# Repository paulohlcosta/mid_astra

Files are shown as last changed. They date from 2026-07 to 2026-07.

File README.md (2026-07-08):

Fazer a leitura dos sinais do computador de bordo MID do Astra - 1999 a 2011.

Provavelmente você sabe de algum astra que tem o computador de bordo defeituoso. O equipamento original usa lâmpadas halógenas que geram muito calor e uma tela LCD super delicada.
Com um Arduino e algum circuito eletrônico, estou trabalhando numa alternativa para esse equipamento.

[NotebookLM do estudo:](https://notebooklm.google.com/notebook/e0c29d24-7539-4ca7-bbeb-1d556da1ff12)

Melhor referência que encontrei até o momento: <https://github.com/fire1/ArduinoMid>

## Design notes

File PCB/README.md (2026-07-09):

Esquemáticos para impressão da PCB e seus componentes.

Diagrama eletrônico do circuito.

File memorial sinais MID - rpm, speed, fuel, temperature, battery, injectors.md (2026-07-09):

# Technical Memorial: Signal Characterization — Astra MID Reader (Phase 1)

**Device:** Arduino Nano (ATmega328P, 16MHz) / **Vehicle:** Brazilian 1999 Chevrolet Astra (ECM Bosch Motronic 1.5.5) with MID.

---

### PIN 2 — PIN_TACHO

* **Signal description:** Engine crankshaft rotation frequency (tachometer).
* **Signal origin:** Negative square wave emitted by the ECU, conditioned and inverted by an optocoupler PC817 before reaching the Arduino. The resulting signal at the Arduino pin is a positive square wave, active HIGH at rest (`INPUT_PULLUP`), pulsing LOW on each engine event.
* **Electrical characteristics:** Signal shared with the OEM instrument cluster stepper motor driver. Series resistor 10kΩ on optocoupler LED input. Optocoupler collector pulled up internally by Arduino `INPUT_PULLUP` (~50kΩ to 5V). Pull-up resistor on optocoupler LED side measured at ~2.2kΩ recommended for reliable LED saturation at 5mA.
* **Observed behavior:** At idle (~950–1000 RPM), period measured at ~31.500µs (~31.7Hz). At 2600 RPM, period drops to ~11.500µs (~86Hz). Signal is stable and consistent across sessions. Pulse count per window of 500ms at idle: 16–19 pulses, consistent with ~32Hz and two pulses per crankshaft revolution (motor 4-cylinder, 2 events per cycle). Between 15 and 150 pulses can occur within each 500ms interval depending on engine speed.
* **Interrupt:** External interrupt INT0, FALLING edge, `attachInterrupt()`.
* **RPM calculation:** $$\text{RPM} = \frac{60 \times 10^6}{\text{period}(\mu\text{s}) \times N_{\text{teeth}}}$$
  where $N_{\text{teeth}}$ is the number of reluctor teeth per revolution — confirmed empirically at 2 events/rev for this engine.
* **Notes for future development:** This signal is reliable and fully characterized. For a future OBD computer, this pin can directly drive RPM display, shift-light logic, and engine load calculations. Timer Input Capture (ICP1, pin 8) should be preferred over external interrupt in a redesign, as it timestamps edges in hardware with zero jitter, freeing CPU cycles and improving accuracy at high RPM.

---

### PIN 3 — PIN_SPEED

* **Signal description:** Vehicle road speed (speedometer).
* **Signal origin:** Presumably identical architecture to PIN_TACHO — negative square wave from ECU, conditioned via optocoupler, shared with OEM instrument cluster.
* **Electrical characteristics:** Same isolation and protection scheme as PIN_TACHO. `INPUT_PULLUP` active.
* **Observed behavior:** Signal confirmed functional during vehicle movement. The frequency of pulses can be user to determine vehycle speed.
* **Interrupt:** External interrupt INT1, FALLING edge, `attachInterrupt()`.
* **Speed calculation:** $$V_{\text{km/h}} = \frac{3600 \times 10^6}{\text{period}(\mu\text{s}) \times K}$$
  where $K$ is the pulses-per-kilometer constant. For this project $K$ = 15600.

---

### PIN 5 — PIN_TEMP_PWM

* **Signal description:** Engine coolant temperature indicator, as seen by the OEM instrument cluster stepper motor driver.
* **Signal origin:** PWM signal generated internally by the OEM instrument cluster to drive the stepper motor of the temperature gauge. The ECU sends temperature data to the cluster via a separate bus (likely serial or analog); the cluster translates this into a PWM duty cycle to position the stepper motor pointer. The Arduino taps this PWM line directly at the cluster connector.
* **Electrical characteristics:** No optocoupler isolation. Signal voltage is 5V-compatible (cluster logic level). `INPUT_PULLUP` active. Signal absent (pin stays HIGH via pull-up) when cluster is unpowered or when coolant temperature is below the gauge's lower threshold (~70°C), because the stepper motor driver receives no movement command in that range.
* **Observed behavior:**

| Temperature (°C) | TEMP_PWM Duty (%) | Observation |
| :--- | :--- | :--- |
| <70 (cold engine) | 90.2% (fixed) | Pointer at rest, no stepper command |
| 70 | 89.5% | Pointer begins to move |
| 80 | 72.0% | Normal operating range |
| 85 | 64.0% | Radiator fan #1 activated by ECU |
| ~90 (extrapolated) | ~55% | Estimated, not yet logged |

* **Signal period:** stable at ~9.920–9.940µs (~100Hz) across all conditions. This frequency is the fixed oscillator clock of the stepper motor driver IC inside the cluster. The duty cycle encodes the pointer position command.
* **Logic polarity:** Signal is logically inverted relative to temperature. Higher temperature → lower duty cycle. With `INPUT_PULLUP`, the duty measured is the HIGH time; the ECU-commanded LOW time increases with temperature. Effective temperature-encoding duty: $\text{duty\_real} = 100\% - \text{duty\_measured}$.
* **Read method:** `pulseIn()` executed once every 10 seconds (`TEMP_INTERVAL`), to avoid blocking the main loop and corrupting `INJ_PULSE` capture. This cadence is more than sufficient given the thermal time constant of the cooling system (observed ~4 minutes from 70°C to 85°C).
* **Notes for future development:** A multi-point calibration table mapping $\text{duty\_real} to °C should be built from controlled logged sessions with a reference thermometer. Preliminary curve suggests linear or mildly nonlinear behavior between 70°C and ~110°C. The 100Hz fixed period is a reliable sanity-check signal — if period deviates significantly from ~10ms, it indicates cluster power loss or hardware fault. In a redesign, this pin should be read via PCINT2 with asynchronous edge capture to completely eliminate `pulseIn()` blocking.

---

### PIN 8 — PIN_INJECTOR

* **Signal description:** Fuel injector signal analysis.
* **Signal origin:** Negative pulse signal from ECU driving the fuel injectors. Signal is non-periodic — each pulse is an independent event corresponding to one injection event. The injector pulse duration is fixed, meaning that only the pulse frequency varies to control fuel delivery; higher frequency indicates higher fuel consumption. Signal conditioned via optocoupler PC817.
* **Electrical characteristics:** Same optocoupler isolation as TACHO. `INPUT_PULLUP` active. With `INPUT_PULLUP`, pin rests HIGH; injector opening event pulls pin LOW.
* **Observed behavior:** Between 15 and 150 injector pulses can occur within each 500ms measurement window. Current baseline calculation assumes a consumption rate of 22,700 pulses per liter of fuel injected, although this scaling factor can be modified or calibrated later.
* **Notes for future development:** This hardware channel requires the use of **Timer1 Input Capture (ICP1)** to properly monitor the incoming pulse events without missing rapid triggers.

---

### PIN A2 — PIN_BATT

* **Signal description:** Vehicle electrical system voltage (battery / alternator).
* **Signal origin:** Direct resistive voltage divider tap from the vehicle 12V bus. No isolation.
* **Electrical characteristics:** Voltage divider ratio calibrated empirically. Observed range: 0.00V (ignition off, Arduino unpowered) to 14.09V (alternator charging at ~2600 RPM). Resting battery voltage: ~12.20–12.23V (engine off, ignition on). Charging voltage: 13.60–14.09V (engine running, consistent with a healthy alternator regulator setpoint of ~14.2V ±0.3V).
* **Observed behavior:** Voltage drop to ~10.14V observed at engine crank (starter motor inrush current). Instantaneous drop to ~13.60–13.68V correlated with radiator fan activation, consistent with ~15–20A fan motor load. Voltage collapse to ~1.09V immediately at ignition key-off, reaching 0.00V within ~1.5 seconds as filter capacitors discharge.
* **Notes for future development:** ADC reference on the Arduino Nano is tied to VCC (5V), which itself may fluctuate with USB/vehicle supply variations. For improved accuracy, use the internal 1.1V bandgap reference with a better-ratio divider, or use an external precision voltage reference (e.g., LM4040). A low-pass RC filter (e.g., 10kΩ + 100µF) on the divider output will suppress alternator ripple and starter transients before the ADC pin.

---

### PIN A0 — PIN_FUEL

* **Signal description:** Fuel tank level.
* **Signal origin:** Potentiometer-type resistive sensor inside the fuel tank. Voltage read via resistive divider at the instrument cluster signal line.
* **Electrical characteristics:** No isolation. Voltage range observed: 5.82V–6.88V across all sessions, with the vehicle presumably at a fixed fuel level (parked). Divider ratio not yet calibrated against a known fuel level.
* **Observed behavior:** Signal is stable with low noise at rest. Minor fluctuations of ±0.06V observed, likely due to ADC noise and small variations in the vehicle supply. No sloshing artifact observed (vehicle stationary throughout all logged sessions).
* **Notes for future development:** Fuel sender resistance curves are nonlinear and vehicle-specific. A minimum 5-point calibration table (empty, 1/4, 1/2, 3/4, full) is required, measured with a reference fuel gauge and known tank volumes. Implement a software moving-average filter (8–16 samples) to suppress sloshing noise during vehicle movement. The observed voltage range of ~5.82–6.88V suggests the divider ratio needs adjustment to use the full ADC range (0–5V), improving resolution from the current ~12-bit effective range to the full 10-bit ADC range.

---

### General Notes for Future On-Board Computer Development

The signal set captured is sufficient to compute in real time: engine RPM, vehicle speed, coolant temperature (after calibration), fuel level (after calibration), battery state, injector frequency, and estimated fuel consumption (based on the fixed pulse-per-liter calculation).

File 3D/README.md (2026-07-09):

Arquivos desenhados para impressão em 3D, prototipagem e afins.

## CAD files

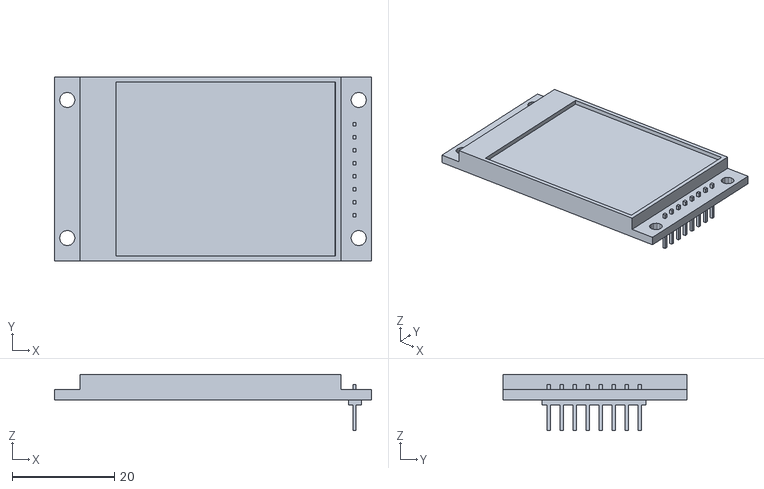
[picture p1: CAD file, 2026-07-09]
3D/display ST7789 2.0inch.stl
62.0 x 36.0 x 11.0

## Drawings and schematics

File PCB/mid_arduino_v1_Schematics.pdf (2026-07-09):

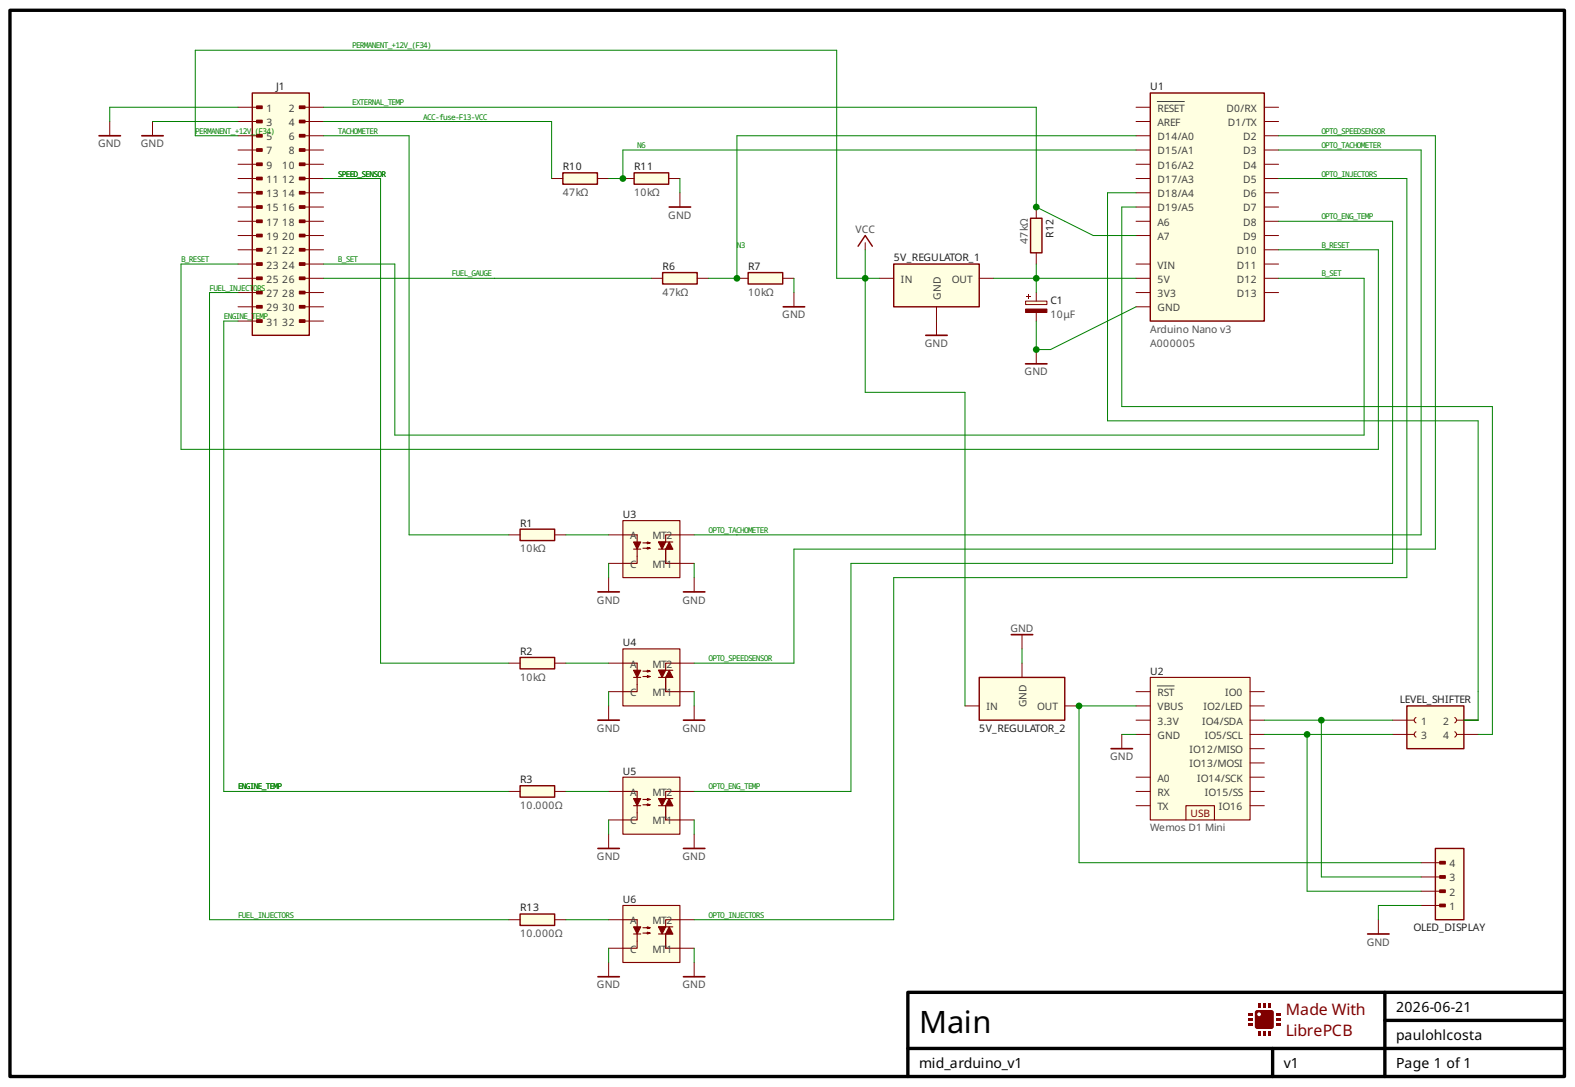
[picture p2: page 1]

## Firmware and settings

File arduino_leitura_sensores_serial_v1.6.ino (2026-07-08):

/*
 * Astra MID Reader - Fase 1 - Rev C
 * Monitora: tacômetro, velocidade, temperatura (PWM), injetor, bateria e combustível.
 * Pinos: TACHO=2 (INT0), SPEED=3 (INT1), TEMP_PWM=5, INJECTOR=8 (ICP1), BATT=A2, FUEL=A0.
 * Injetor usa Timer1 Input Capture (ICP1, pino 8) com alternância de borda por hardware.
 * Optoacoplador PC817 com pull-up: injetor ativo = pino LOW, repouso = HIGH.
 * Borda de DESCIDA = início do pulso, borda de SUBIDA = fim do pulso.
 * Período (descida a descida) e largura calculados inteiramente na ISR via Timer1.
 * Prescaler 8 → resolução 0,5µs por tick. Overflow (~32ms) tratado via contador de 32 bits.
 * TEMP_PWM lido com pulseIn a cada TEMP_INTERVAL ms para minimizar bloqueio no loop.
 * TACHO e SPEED com timeout de 2s para zerar leitura quando sem pulsos.
 * BUTTON_A=D10, BUTTON_B=D12: botões momentâneos que fecham com GND (INPUT_PULLUP).
 */

// -----------------------------------------------------------------------------
// Pinagem
// -----------------------------------------------------------------------------
#define PIN_TACHO       2
#define PIN_SPEED       3
#define PIN_TEMP_PWM    5
#define PIN_INJECTOR    8    // ICP1 — fixo no hardware do ATmega328P
#define PIN_BATT       A2
#define PIN_FUEL       A0
#define PIN_BUTTON_A   10   // Botão A — fecha com GND
#define PIN_BUTTON_B   12   // Botão B — fecha com GND

// -----------------------------------------------------------------------------
// Constantes
// -----------------------------------------------------------------------------
#define TIMEOUT_US          2000000UL
#define INJ_PULSE_MIN_US        200UL   // µs mínimo aceitável
#define INJ_PULSE_MAX_US     200000UL   // µs máximo — filtra injetor travado aberto
#define INJ_HIST                    8
#define LOOP_INTERVAL             200   // ms
#define TEMP_INTERVAL           10000UL
#define PULSEIN_TIMEOUT         30000UL
#define INJ_TIMEOUT_OVF          61UL   // ~2s em overflows do Timer1 (prescaler 8)

// -----------------------------------------------------------------------------
// Variáveis TACHO
// -----------------------------------------------------------------------------
volatile unsigned long tachoLastTime = 0;
volatile unsigned long tachoPeriod   = 0;
volatile unsigned int  tachoPulsos   = 0;

// -----------------------------------------------------------------------------
// Variáveis SPEED
// -----------------------------------------------------------------------------
volatile unsigned long speedLastTime = 0;
volatile unsigned long speedPeriod   = 0;
volatile unsigned int  speedPulsos   = 0;

// -----------------------------------------------------------------------------
// Variáveis INJECTOR (ICP1)
// -----------------------------------------------------------------------------
volatile uint32_t injOverflowCount  = 0;
volatile uint32_t injTicksFall      = 0;
volatile uint32_t injTicksPrevFall  = 0;
volatile unsigned long injPulseUs   = 0;
volatile unsigned long injPeriodUs  = 0;
volatile bool          injReady     = false;
volatile bool          injWaitingRise = false;
volatile unsigned long injHistory[INJ_HIST];
volatile uint8_t       injHistIdx   = 0;
volatile uint32_t      injLastValidOvf = 0;
float fator_consumo = 22700.0;

// -----------------------------------------------------------------------------
// Variáveis TEMP_PWM
// -----------------------------------------------------------------------------
float tempDutyCache    = -1.0;
float tempPeriodoCache =  0.0;
bool  tempValido       = false;

// -----------------------------------------------------------------------------
// ISR — TACHO (INT0, pino 2, FALLING)
// -----------------------------------------------------------------------------
void isrTacho() {
  unsigned long agora = micros();
  tachoPeriod   = agora - tachoLastTime;
  tachoLastTime = agora;
  tachoPulsos++;
}

// -----------------------------------------------------------------------------
// ISR — SPEED (INT1, pino 3, FALLING)
// -----------------------------------------------------------------------------
void isrSpeed() {
  unsigned long agora = micros();
  speedPeriod   = agora - speedLastTime;
  speedLastTime = agora;
  speedPulsos++;
}

// -----------------------------------------------------------------------------
// ISR — Timer1 Overflow
// -----------------------------------------------------------------------------
ISR(TIMER1_OVF_vect) {
  injOverflowCount++;
}

// -----------------------------------------------------------------------------
// ISR — Timer1 Input Capture
// PC817 com pull-up: repouso=HIGH, injetor ativo=LOW
//   borda de DESCIDA (ICES1=0) → início do pulso → salva ticks, alterna para subida
//   borda de SUBIDA  (ICES1=1) → fim do pulso    → calcula largura e período
// -----------------------------------------------------------------------------
ISR(TIMER1_CAPT_vect) {
  uint16_t captura  = ICR1;
  uint32_t ovfLocal = injOverflowCount;

  if ((TIFR1 & (1 << TOV1)) && captura < 0x8000) {
    ovfLocal++;
  }

  uint32_t ticksAgora = (ovfLocal << 16) | captura;

  if (!injWaitingRise) {
    injTicksPrevFall = injTicksFall;
    injTicksFall     = ticksAgora;
    injWaitingRise   = true;
    TCCR1B |= (1 << ICES1);
  } else {
    injWaitingRise = false;
    TCCR1B &= ~(1 << ICES1);

    uint32_t ticksPulso = ticksAgora - injTicksFall;
    unsigned long larguraUs = ticksPulso >> 1;

    if (larguraUs >= INJ_PULSE_MIN_US && larguraUs <= INJ_PULSE_MAX_US) {
      injPulseUs = larguraUs;

      if (injTicksPrevFall > 0) {
        uint32_t ticksPeriodo = injTicksFall - injTicksPrevFall;
        injPeriodUs = ticksPeriodo >> 1;
      }

      injHistory[injHistIdx % INJ_HIST] = larguraUs;
      injHistIdx++;
      injReady = true;
      injLastValidOvf = ovfLocal;
    }
  }
}

// -----------------------------------------------------------------------------
// Leitura TEMP_PWM
// -----------------------------------------------------------------------------
void atualizarTempPWM() {
  unsigned long high = pulseIn(PIN_TEMP_PWM, HIGH, PULSEIN_TIMEOUT);
  unsigned long low  = pulseIn(PIN_TEMP_PWM, LOW,  PULSEIN_TIMEOUT);

  if (high == 0 && low == 0) {
    tempDutyCache    = -1.0;
    tempPeriodoCache =  0.0;
    tempValido       = false;
    return;
  }

  unsigned long periodo = high + low;
  tempDutyCache    = (periodo > 0) ? (float)high / periodo * 100.0 : -1.0;
  tempPeriodoCache = (float)periodo;
  tempValido       = true;
}

// -----------------------------------------------------------------------------
// Setup
// -----------------------------------------------------------------------------
void setup() {
  Serial.begin(115200);

  pinMode(PIN_TACHO,    INPUT_PULLUP);
  pinMode(PIN_SPEED,    INPUT_PULLUP);
  pinMode(PIN_TEMP_PWM, INPUT_PULLUP);
  pinMode(PIN_INJECTOR, INPUT_PULLUP);
  pinMode(PIN_BUTTON_A, INPUT_PULLUP);
  pinMode(PIN_BUTTON_B, INPUT_PULLUP);

  attachInterrupt(digitalPinToInterrupt(PIN_TACHO), isrTacho, FALLING);
  attachInterrupt(digitalPinToInterrupt(PIN_SPEED), isrSpeed, FALLING);

  TCCR1A = 0;
  TCCR1B = 0;
  TCCR1B |= (1 << CS11);
  TIMSK1 |= (1 << ICIE1);
  TIMSK1 |= (1 << TOIE1);

  atualizarTempPWM();

  Serial.println("@");
  Serial.print(F("=== ASTRA MID READER - FASE 1 Rev C ==="));
  Serial.println(__FILE__);
  Serial.println(F("Aguardando sinais..."));
  Serial.println(F("--------------------------------------------------"));
  Serial.println(F("millis | BATT(V) | FUEL(V) | TACHO_P | SPEED_P | SPEED_PERIOD(us) | TEMP_DUTY(%) | INJ_PULSE_COUNT | BTN_A BTN_B"));
  Serial.println(F("--------------------------------------------------"));
}

// -----------------------------------------------------------------------------
// Loop
// -----------------------------------------------------------------------------
void loop() {
  static unsigned long ultimoLog  = 0;
  static unsigned long ultimoTemp = 0;
  unsigned long agora = millis();

  if (agora - ultimoTemp >= TEMP_INTERVAL) {
    ultimoTemp = agora;
    atualizarTempPWM();
  }

  if (agora - ultimoLog < LOOP_INTERVAL) return;
  ultimoLog = agora;

  // --- TACHO ---
  unsigned int  tachoP;
  unsigned long tachoT, tachoLast;
  noInterrupts();
    tachoP      = tachoPulsos;
    tachoT      = tachoPeriod;
    tachoLast   = tachoLastTime;
    tachoPulsos = 0;
  interrupts();
  if ((micros() - tachoLast) > TIMEOUT_US) tachoT = 0;

  // --- SPEED ---
  unsigned int  speedP;
  unsigned long speedT, speedLast;
  noInterrupts();
    speedP      = speedPulsos;
    speedT      = speedPeriod;
    speedLast   = speedLastTime;
    speedPulsos = 0;
  interrupts();
  if ((micros() - speedLast) > TIMEOUT_US) speedT = 0;

  // --- INJECTOR ---
  unsigned long injPulseLocal  = 0;
  unsigned long injPeriodLocal = 0;
  bool          injReadyLocal  = false;
  uint8_t       injCountLocal  = 0;
  unsigned long injHistLocal[INJ_HIST];
  uint32_t      injLastOvfLocal = 0;

  noInterrupts();
    injPulseLocal   = injPulseUs;
    injPeriodLocal  = injPeriodUs;
    injReadyLocal   = injReady;
    injReady        = false;
    injCountLocal   = injHistIdx;
    injHistIdx      = 0;
    for (uint8_t i = 0; i < min((uint8_t)INJ_HIST, injCountLocal); i++)
      injHistLocal[i] = injHistory[i];
    injLastOvfLocal = injLastValidOvf;
  interrupts();

  // --- BATT e FUEL ---
  float batt = analogRead(PIN_BATT) * (5.0 / 1023.0) * 5.7;
  float fuel = analogRead(PIN_FUEL) * (5.0 / 1023.0) * 5.7;

  // --- BOTÕES (0=aberto, 1=fechado) ---
  uint8_t btnA = (digitalRead(PIN_BUTTON_A) == LOW) ? 1 : 0;
  uint8_t btnB = (digitalRead(PIN_BUTTON_B) == LOW) ? 1 : 0;

  // --- LOG ---
  Serial.print(agora);
  Serial.print(F("|"));
  Serial.print(batt, 2);
  Serial.print(F("|"));
  Serial.print(fuel, 2);
  Serial.print(F("|"));
  Serial.print(tachoP);
  Serial.print(F("|"));
  Serial.print(speedP);
  Serial.print(F("|"));
  Serial.print(speedT);
  Serial.print(F("us "));
  Serial.print(speedT > 0 ? 1000000.0 / speedT : 0.0, 1);
  Serial.print(F("Hz|"));

  if (!tempValido) {
    Serial.print(F("-1.0%|"));
  } else {
    Serial.print(tempDutyCache, 1);
    Serial.print(F("%|"));
  }

  uint32_t injPulsosJanela = injCountLocal;
  Serial.print(injPulsosJanela);
  Serial.print(F("|"));
  Serial.print(btnA);
  Serial.println(btnB);
}
